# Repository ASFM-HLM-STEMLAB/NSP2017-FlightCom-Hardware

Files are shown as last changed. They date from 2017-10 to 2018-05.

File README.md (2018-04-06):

# NSP2017-FlightCom-Hardware 
ASFM Near Space Program 2017 - Flight Computer Hardware for HLM1 Capsule

- Designed in Autodesk Eagle.
- Uses Particle Electron as the master Micro Controller Unit

## Files
* HLM1_CNC : 
	This files are for creating a prototype board using a CNC such as shapeoko.
* HLM1_Oursourced : 
	This files are for sending the board to a fab house to be made such as OshPark

## PCB Manufacturing
* You may order a PCB from our [OSHPARK PROJECT R1.0](https://www.oshpark.com/projects/XPm0Xe82)
* You may order a PCB from our [OSHPARK PROJECT R2.1](https://www.adafruit.com/product/3686)
* NOTE: R2.1 includes XBee Radio. GPS IO changed to software serial.

##### Designed and created at ASFM Monterrey Mexico, 2017-2018 @ Humberto Lobo Morales STEM LAB

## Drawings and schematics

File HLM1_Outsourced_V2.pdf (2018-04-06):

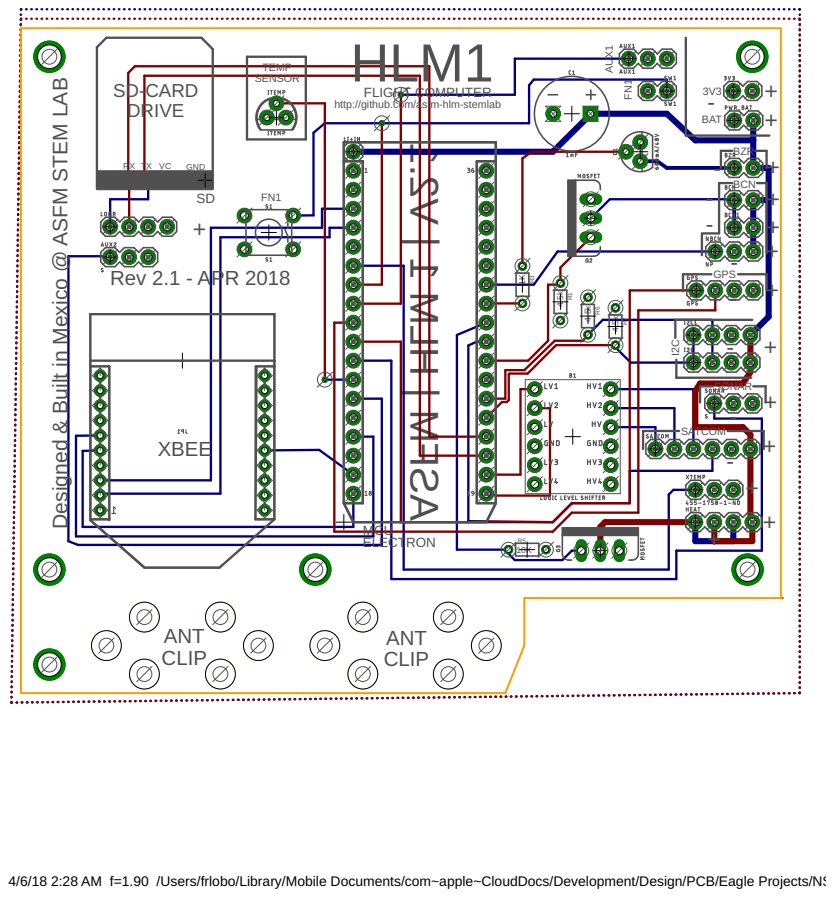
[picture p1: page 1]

4/6/18 2:28 AM f=1.90 /Users/frlobo/Library/Mobile Documents/com~apple~CloudDocs/Development/Design/PCB/Eagle Projects/NSP2/HLM1_Outsourced_V2.brd

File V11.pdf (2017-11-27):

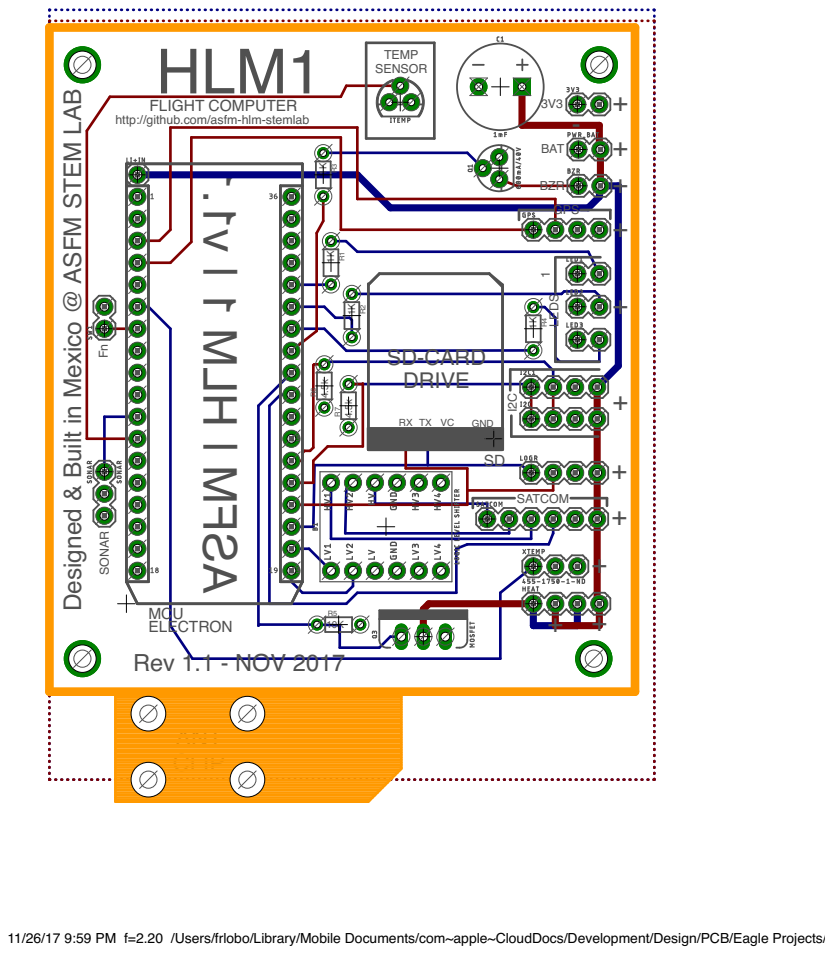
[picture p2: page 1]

FLIGHT COMPUTER
http://github.com/asfm-hlm-stemlab

DRIVE

RX TX VC GND

11/26/17 9:59 PM f=2.20 /Users/frlobo/Library/Mobile Documents/com~apple~CloudDocs/Development/Design/PCB/Eagle Projects/NSP2/HLM1_Outsourced.brd

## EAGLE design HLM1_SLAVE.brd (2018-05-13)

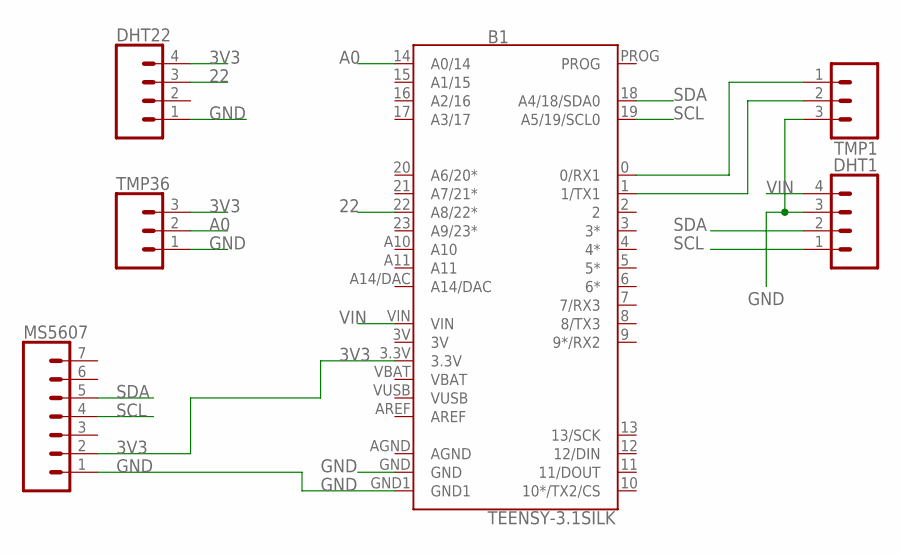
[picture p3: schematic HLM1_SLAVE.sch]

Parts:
B1: TEENSY-3.1SILK; TEENSY-3.1
DHT1, DHT22: CONN_04; 1X04
MS5607: CONN_07; 1X07
TMP1, TMP36: CONN_03; 1X03

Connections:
3V: B1.3V
3V3: B1.3.3V, DHT22.4, MS5607.2, TMP36.3
22: B1.22 (A8/22*), DHT22.3
A0: B1.14 (A0/14), TMP36.2
AGND: B1.AGND
GND: B1.GND, B1.GND1, DHT1.3, DHT22.1, MS5607.1, TMP1.3, TMP36.1
unnamed: B1.0 (0/RX1), TMP1.1
unnamed: B1.1 (1/TX1), TMP1.2
SCL: B1.19 (A5/19/SCL0), DHT1.1, MS5607.4
SDA: B1.18 (A4/18/SDA0), DHT1.2, MS5607.5
VBAT: B1.VBAT
VIN: B1.VIN, DHT1.4
VUSB: B1.VUSB

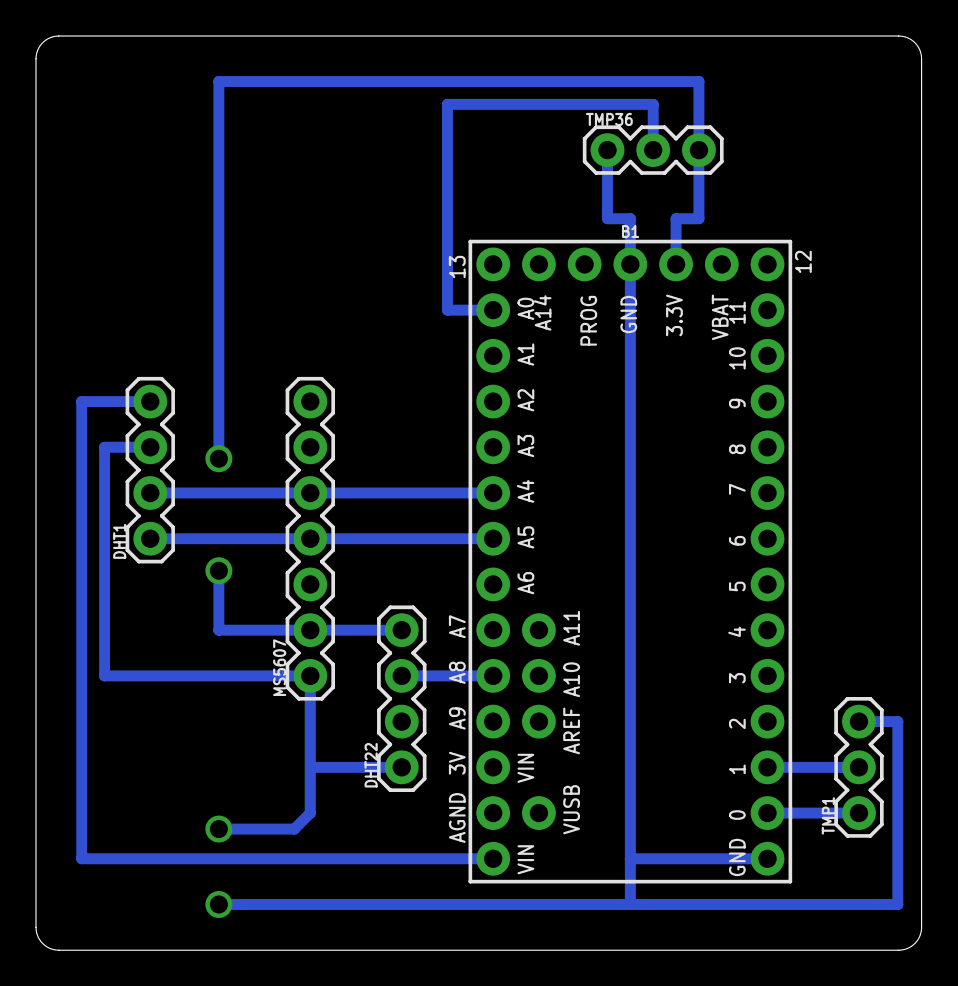
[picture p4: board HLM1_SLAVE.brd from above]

Board: 2 copper layers, 49.2 x 50.8 mm, 6 parts (0 on the bottom side), 9 nets.

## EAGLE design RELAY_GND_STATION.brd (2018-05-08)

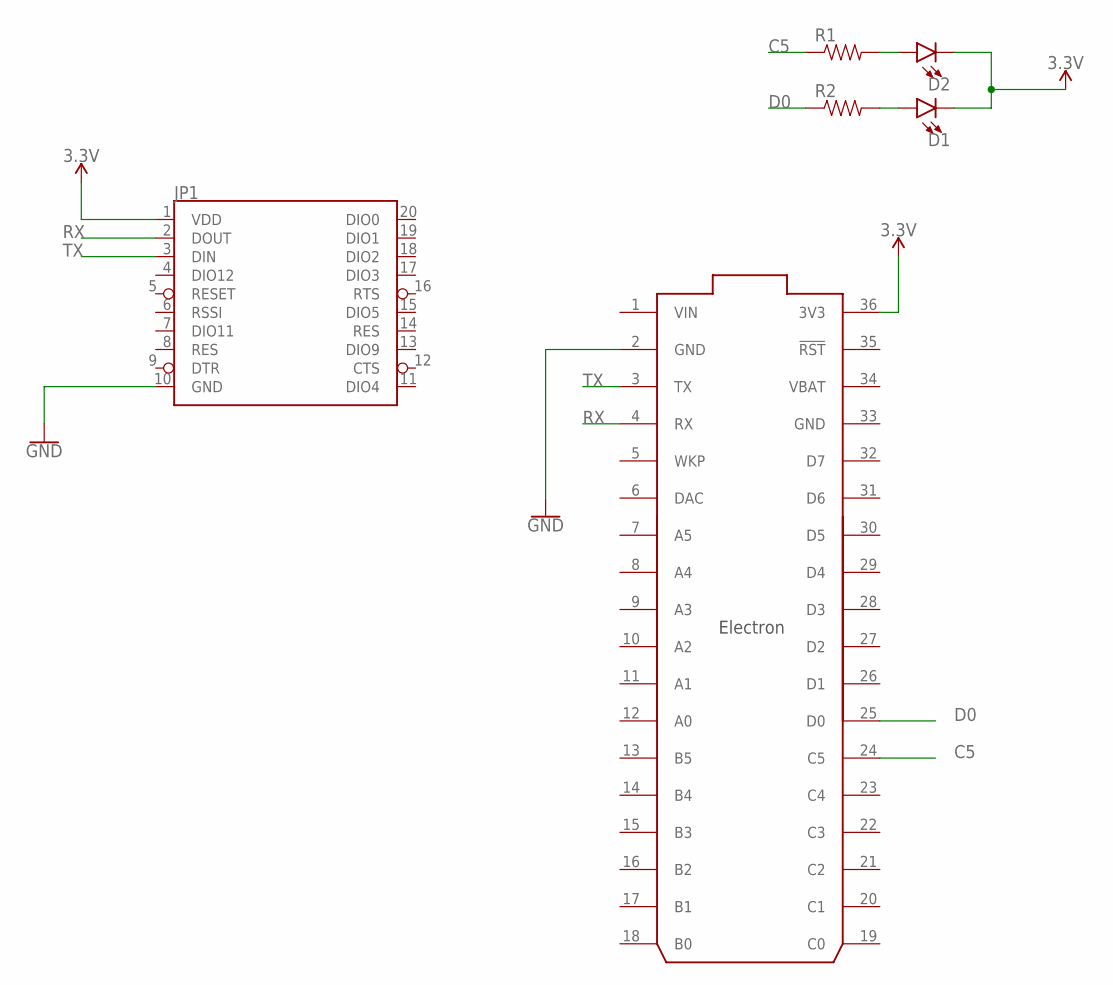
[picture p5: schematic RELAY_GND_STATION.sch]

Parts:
D1, D2: LED-3MM-NO_SILK; LED_3MM-NS
JP1: XBEELONGPAD; XBEE-LONGPAD
R1, R2: RESISTORKIT; AXIAL-0.3-KIT
U$1: ELECTRON_WITH_HEADERS; ELECTRON

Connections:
3.3V: D1.K (C), D2.K (C), JP1.1 (VDD), U$1.36 (3V3)
C5: R1.P$1 (1), U$1.24 (C5)
D0: R2.P$1 (1), U$1.25 (D0)
GND: JP1.10 (GND), U$1.2 (GND), U$1.33 (GND)
unnamed: D2.A, R1.P$2 (2)
unnamed: D1.A, R2.P$2 (2)
RX: JP1.2 (DOUT), U$1.4 (RX)
TX: JP1.3 (DIN), U$1.3 (TX)
VBAT: U$1.34 (VBAT)
VIN: U$1.1 (VIN)

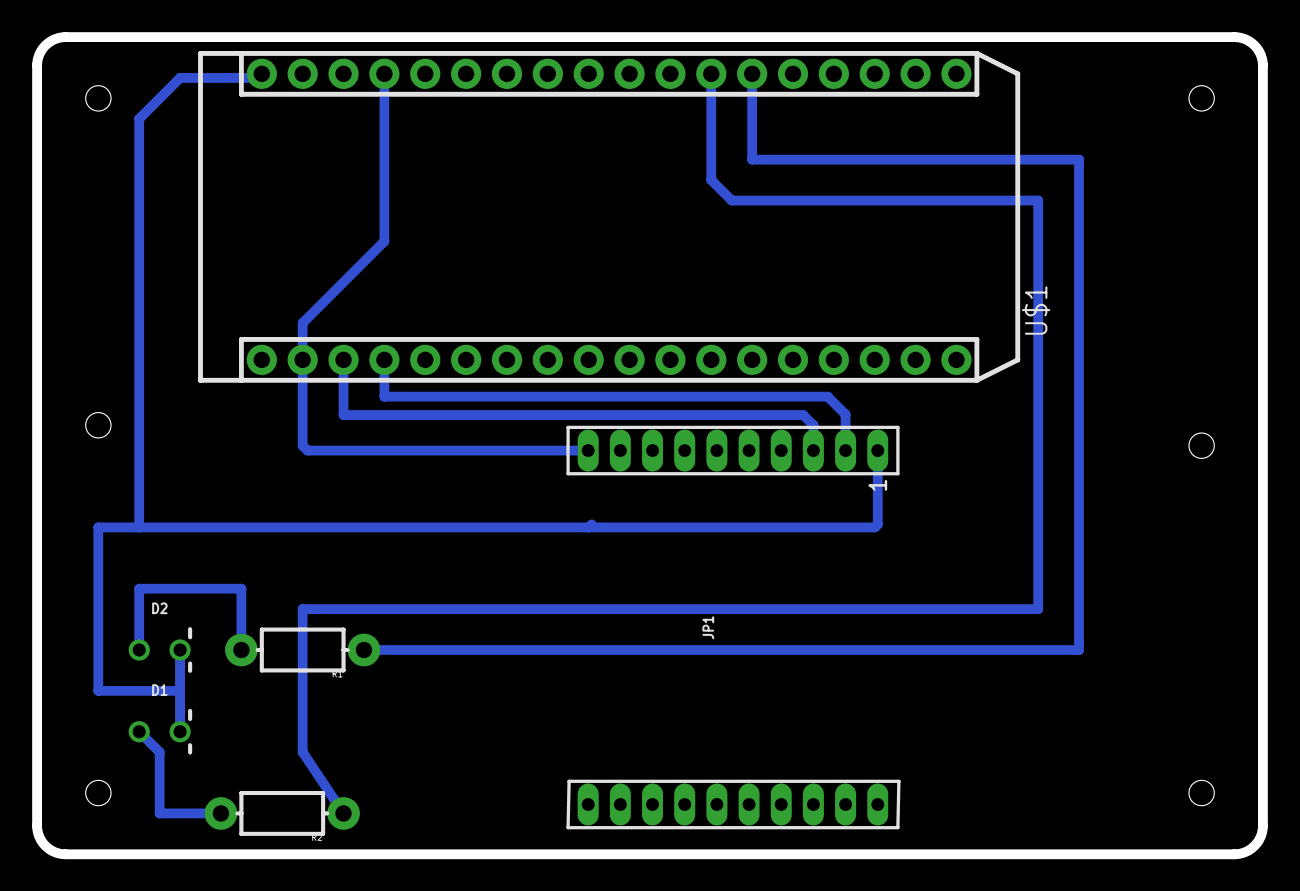
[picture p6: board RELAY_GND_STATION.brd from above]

Board: 2 copper layers, 76.2 x 50.8 mm, 6 parts (0 on the bottom side), 8 nets.

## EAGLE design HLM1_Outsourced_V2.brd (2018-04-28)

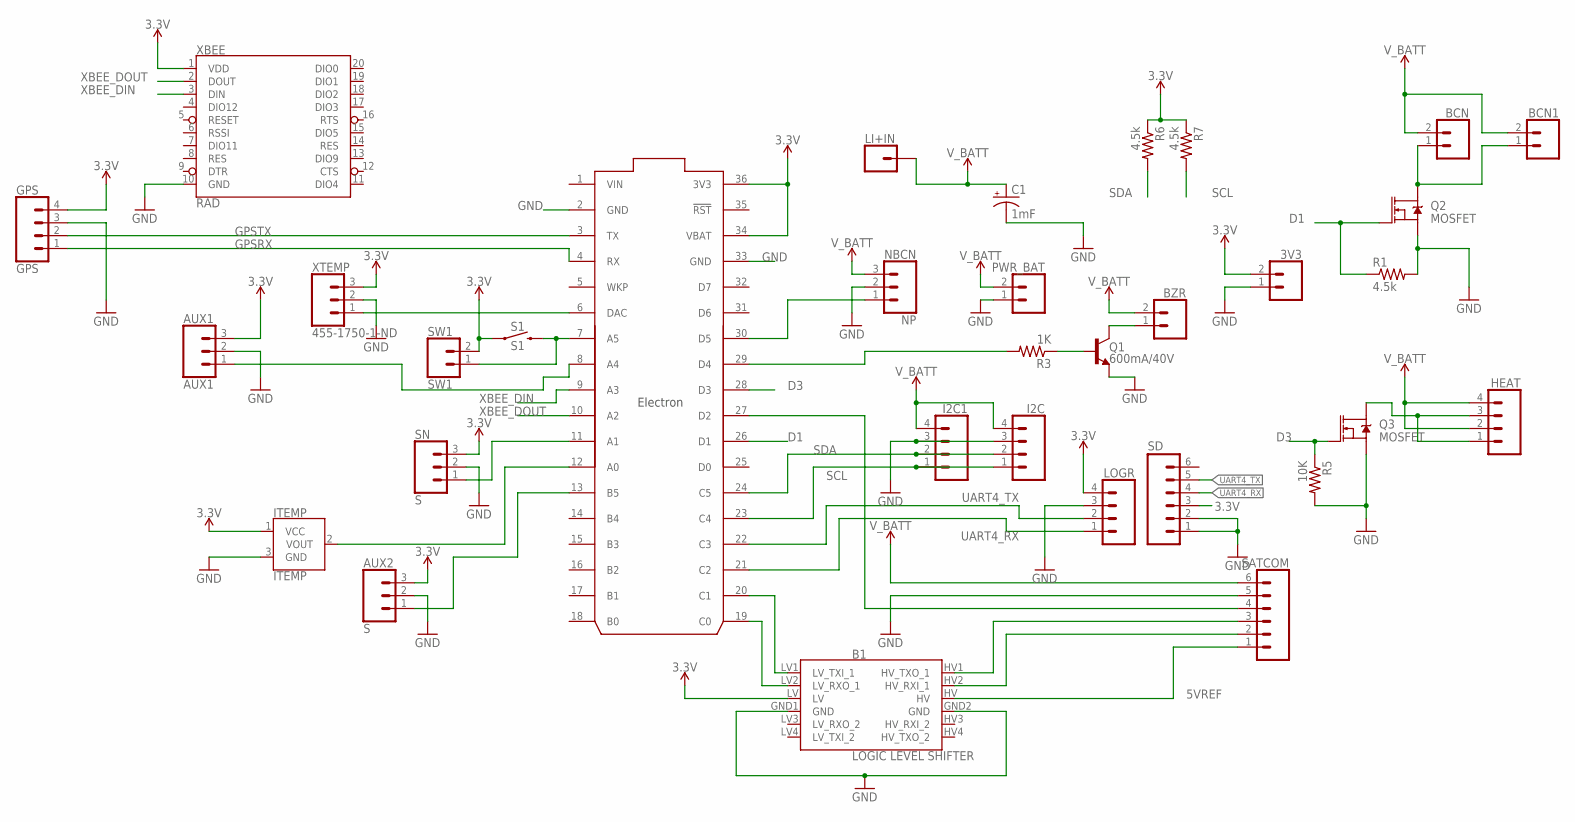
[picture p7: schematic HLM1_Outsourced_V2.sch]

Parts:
3V3: CONN_02; 1X02
AUX1: AUX1; 1X03
AUX2: S; 1X03
B1: LOGIC LEVEL SHIFTER; SPARKFUN_LOGIC_LEVEL_CONVERTER
BCN, BCN1: CONN_02; 1X02
BZR: CONN_02; 1X02
C1: 1mF; CPOL-RADIAL-5MM-10MM
GPS: GPS; 1X04
HEAT: CONN_04; 1X04
I2C, I2C1: CONN_04; 1X04
ITEMP: ITEMP; TO-92
LI+IN: CONN_01; 1X01
LOGR: CONN_04; 1X04
MCU: ELECTRON
NBCN: NP; 1X03
PWR_BAT: CONN_02; 1X02
Q1: 600mA/40V; TO-92
Q2, Q3: MOSFET; TO220V
R1, R6, R7: 4.5k; 1/6W-RES
R3: 1K; 1/6W-RES
R5: 10K; 1/6W-RES
S1: S1; TACTILE_SWITCH_PTH_6.0MM
SATCOM: CONN_06SILK_FEMALE_PTH; 1X06@1
SD: M06NO_SILK_FEMALE_PTH; 1X06_NO_SILK
SN: S; 1X03
SW1: SW1; 1X02
XBEE: RAD; XBEE-LONGPAD
XTEMP: 455-1750-1-ND; 1X03

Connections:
3.3V: 3V3.2, AUX1.3, AUX2.3, B1.LV, GPS.4, ITEMP.1 (VCC), LOGR.4, MCU.34 (VBAT), MCU.36 (3V3), R6.1, R7.1, S1.1, SD.3, SN.3, SW1.2, XBEE.1 (VDD), XTEMP.3
5VREF: B1.HV, SATCOM.1
D1: MCU.26 (D1), Q2.1 (G), R1.1
D3: MCU.28 (D3), Q3.1 (G), R5.1
GND: 3V3.1, AUX1.2, AUX2.2, B1.GND1 (GND), B1.GND2 (GND), C1.-, GPS.3, I2C.3, I2C1.3, ITEMP.3 (GND), LOGR.3, MCU.2 (GND), MCU.33 (GND), NBCN.2, PWR_BAT.1, Q1.3 (E), Q2.3 (S), Q3.3 (S), R1.2, R5.2, SATCOM.5, SD.1, SD.2, SN.2, XBEE.10 (GND), XTEMP.2
GPSRX: GPS.1, MCU.4 (RX)
GPSTX: GPS.2, MCU.3 (TX)
IRWKP: MCU.27 (D2), SATCOM.4
unnamed: MCU.6 (DAC), XTEMP.1
unnamed: MCU.29 (D4), R3.2
unnamed: Q1.2 (B), R3.1
unnamed: MCU.30 (D5), NBCN.1
unnamed: B1.LV1 (LV_TXI_1), MCU.20 (C1)
unnamed: B1.LV2 (LV_RXO_1), MCU.19 (C0)
unnamed: BZR.1, Q1.1 (C)
unnamed: B1.HV1 (HV_TXO_1), SATCOM.3
unnamed: HEAT.1, HEAT.3, Q3.2 (D)
unnamed: BCN.1, BCN1.1, Q2.2 (D)
unnamed: B1.HV2 (HV_RXI_1), SATCOM.2
unnamed: MCU.7 (A5), S1.3 (2), SW1.1
unnamed: MCU.11 (A1), SN.1
unnamed: ITEMP.2 (VOUT), MCU.12 (A0)
unnamed: AUX2.1, MCU.13 (B5)
unnamed: AUX1.1, MCU.8 (A4)
SCL: I2C.1, I2C1.1, MCU.23 (C4), R7.2
SDA: I2C.2, I2C1.2, MCU.24 (C5), R6.2
UART4_RX: LOGR.1, MCU.21 (C2), SD.4
UART4_TX: LOGR.2, MCU.22 (C3), SD.5
VIN: MCU.1 (VIN)
V_BATT: BCN.2, BCN1.2, BZR.2, C1.+, HEAT.2, HEAT.4, I2C.4, I2C1.4, LI+IN.1, NBCN.3, PWR_BAT.2, SATCOM.6
XBEE_DIN: MCU.9 (A3), XBEE.3 (DIN)
XBEE_DOUT: MCU.10 (A2), XBEE.2 (DOUT)

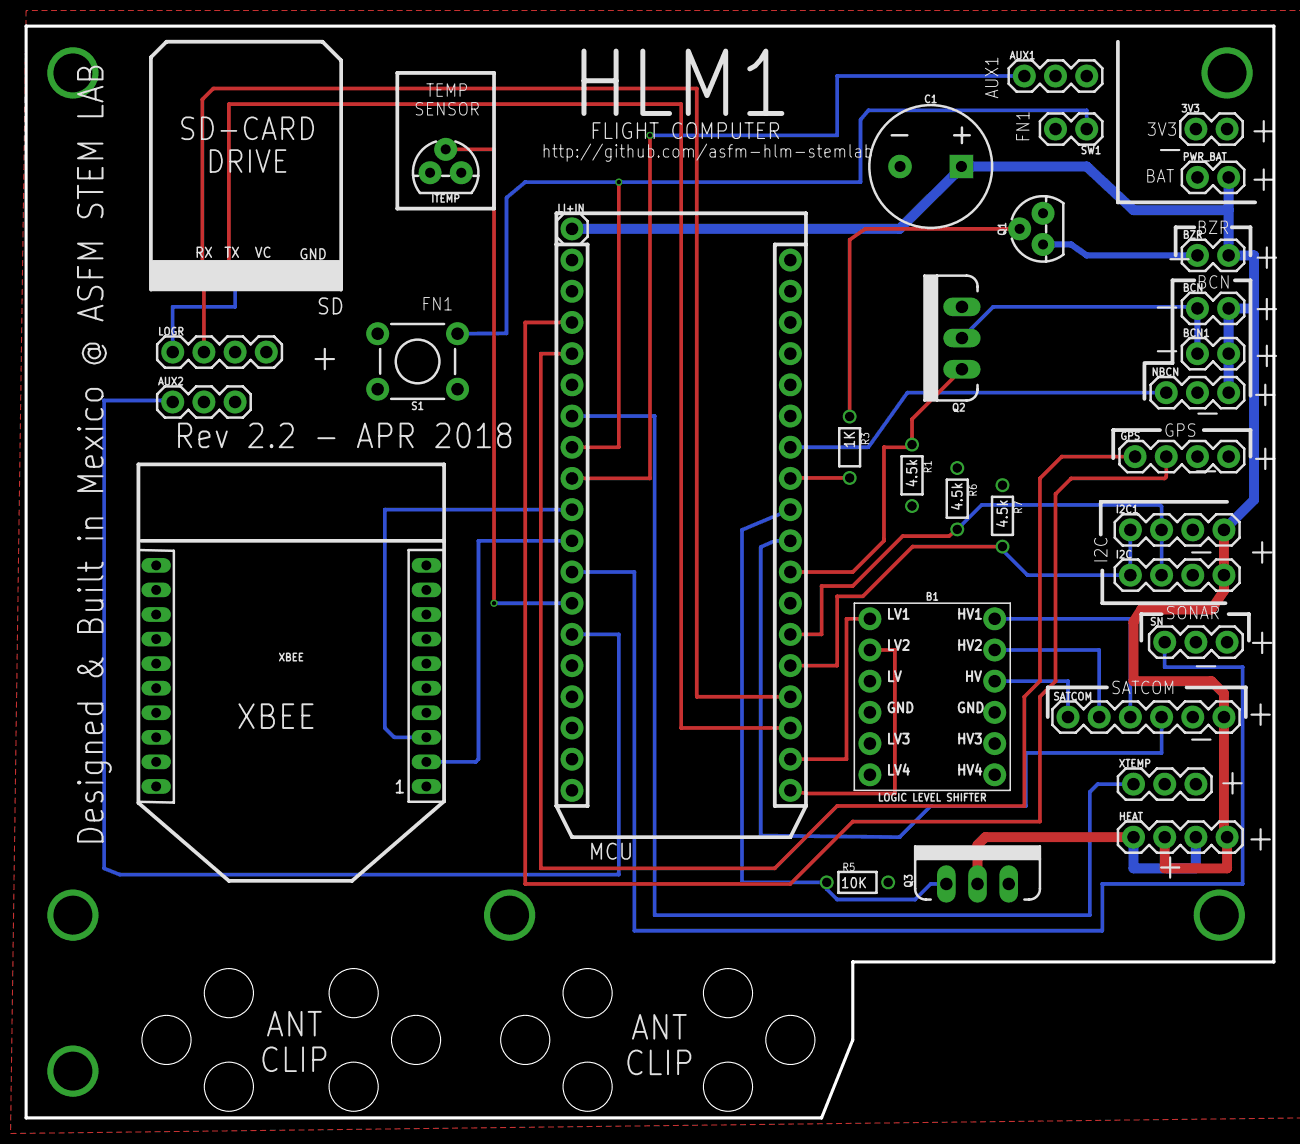
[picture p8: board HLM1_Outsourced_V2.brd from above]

Board: 2 copper layers, 101.6 x 88.9 mm, 33 parts (0 on the bottom side), 31 nets.

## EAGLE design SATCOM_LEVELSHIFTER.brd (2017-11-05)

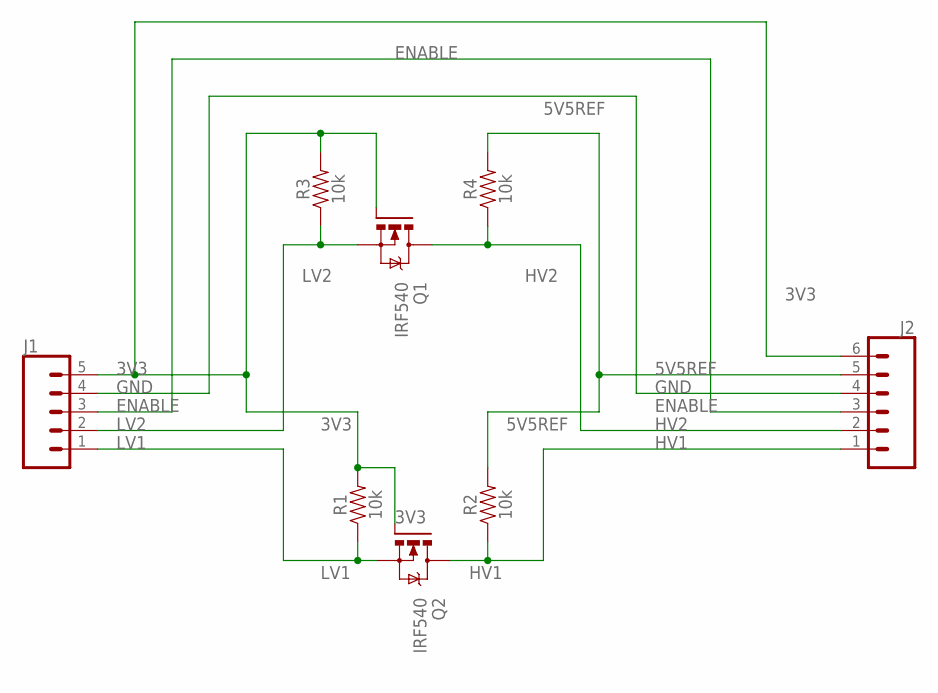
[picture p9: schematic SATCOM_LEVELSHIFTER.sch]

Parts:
J1: CONN_05PTH_LONGPADS; 1X05_LONGPADS
J2: CONN_06LONGPADS; 1X06_LONGPADS
Q1, Q2: IRF540; TO220BV
R1, R2, R3, R4: 10k; AXIAL-0.3-KIT

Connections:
3V3: J1.5, J2.6, Q1.G, Q2.G, R1.P$2 (2), R3.P$2 (2)
5V5REF: J2.5, R2.P$2 (2), R4.P$2 (2)
ENABLE: J1.3, J2.3
GND: J1.4, J2.4
HV1: J2.1, Q2.D, R2.P$1 (1)
HV2: J2.2, Q1.D, R4.P$1 (1)
LV1: J1.1, Q2.S, R1.P$1 (1)
LV2: J1.2, Q1.S, R3.P$1 (1)

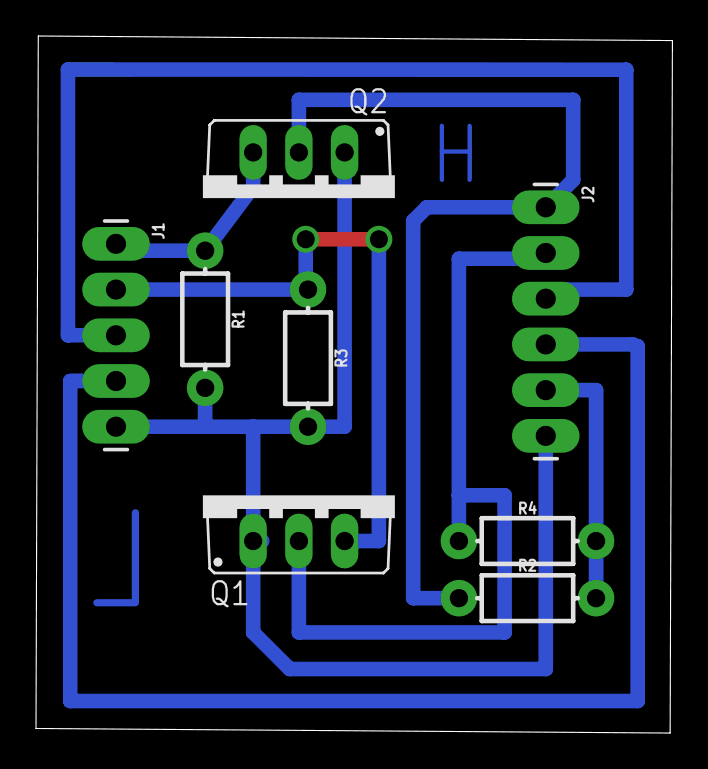
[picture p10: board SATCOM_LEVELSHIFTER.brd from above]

Board: 2 copper layers, 35.4 x 38.7 mm, 8 parts (0 on the bottom side), 8 nets.

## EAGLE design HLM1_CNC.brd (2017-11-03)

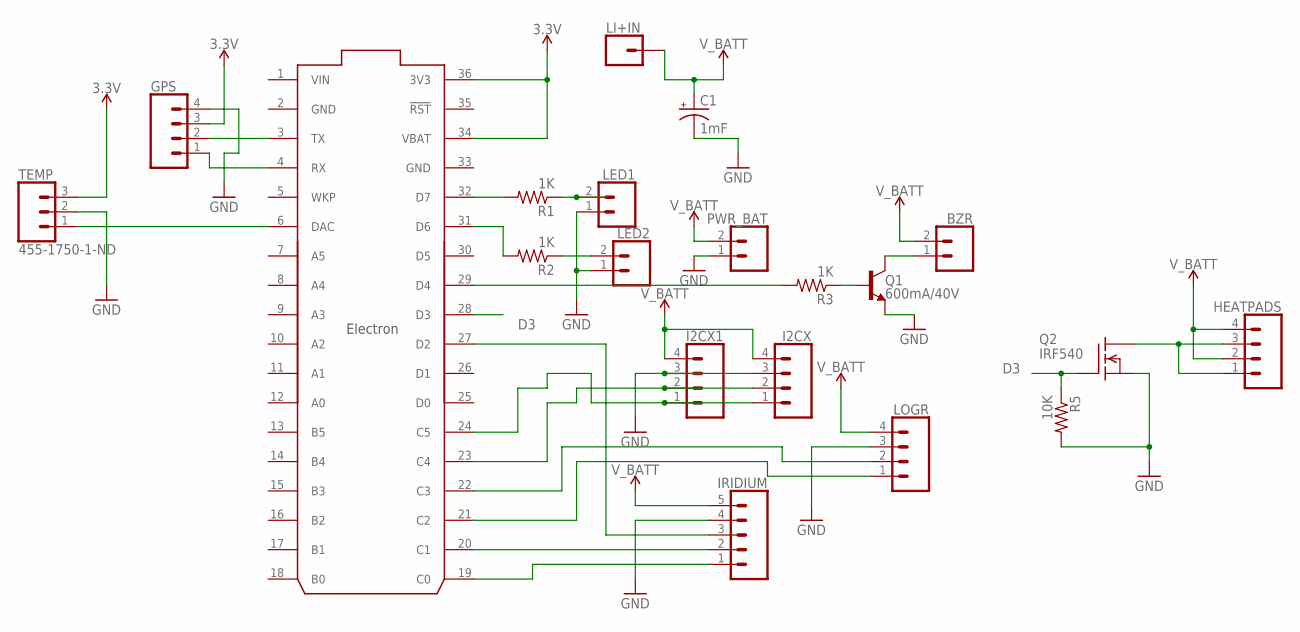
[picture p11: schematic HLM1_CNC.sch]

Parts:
BZR: CONN_02; 1X02
C1: 1mF; CPOL-RADIAL-5MM-10MM
GPS: CONN_04; 1X04
HEATPADS: CONN_04; 1X04
I2CX, I2CX1: CONN_04; 1X04
IRIDIUM: CONN_05; 1X05
LED1, LED2: CONN_02; 1X02
LI+IN: CONN_01; 1X01
LOGR: CONN_04; 1X04
PWR_BAT: CONN_02; 1X02
Q1: 600mA/40V; TO-92
Q2: IRF540; TO220
R1, R2, R3: 1K; 1/6W-RES
R5: 10K; 1/6W-RES
TEMP: 455-1750-1-ND; 1X03
U$1: ELECTRON_WITH_HEADERS; ELECTRON

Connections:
3.3V: GPS.3, TEMP.3, U$1.34 (VBAT), U$1.36 (3V3)
BASE: Q1.2 (B), R3.1
D3: Q2.1 (G), R5.1, U$1.28 (D3)
GND: C1.-, GPS.4, I2CX.3, I2CX1.3, IRIDIUM.4, LED1.1, LED2.1, LOGR.3, PWR_BAT.1, Q1.3 (E), Q2.3 (S), R5.2, TEMP.2, U$1.2 (GND), U$1.33 (GND)
IRWKP: IRIDIUM.3, U$1.27 (D2)
unnamed: TEMP.1, U$1.6 (DAC)
unnamed: R1.2, U$1.32 (D7)
unnamed: R3.2, U$1.29 (D4)
unnamed: LED1.2, R1.1
unnamed: BZR.1, Q1.1 (C)
unnamed: HEATPADS.1, HEATPADS.3, Q2.2 (D)
unnamed: R2.2, U$1.31 (D6)
unnamed: IRIDIUM.2, U$1.20 (C1)
unnamed: I2CX.1, I2CX1.1, U$1.24 (C5)
unnamed: LED2.2, R2.1
RX: GPS.1, U$1.4 (RX)
SDA: I2CX.2, I2CX1.2, U$1.23 (C4)
TX: GPS.2, U$1.3 (TX)
UART4_RX: LOGR.1, U$1.21 (C2)
UART4_TX: LOGR.2, U$1.22 (C3)
UART5_RX: IRIDIUM.1, U$1.19 (C0)
VIN: U$1.1 (VIN)
V_BATT: BZR.2, C1.+, HEATPADS.2, HEATPADS.4, I2CX.4, I2CX1.4, IRIDIUM.5, LI+IN.1, LOGR.4, PWR_BAT.2

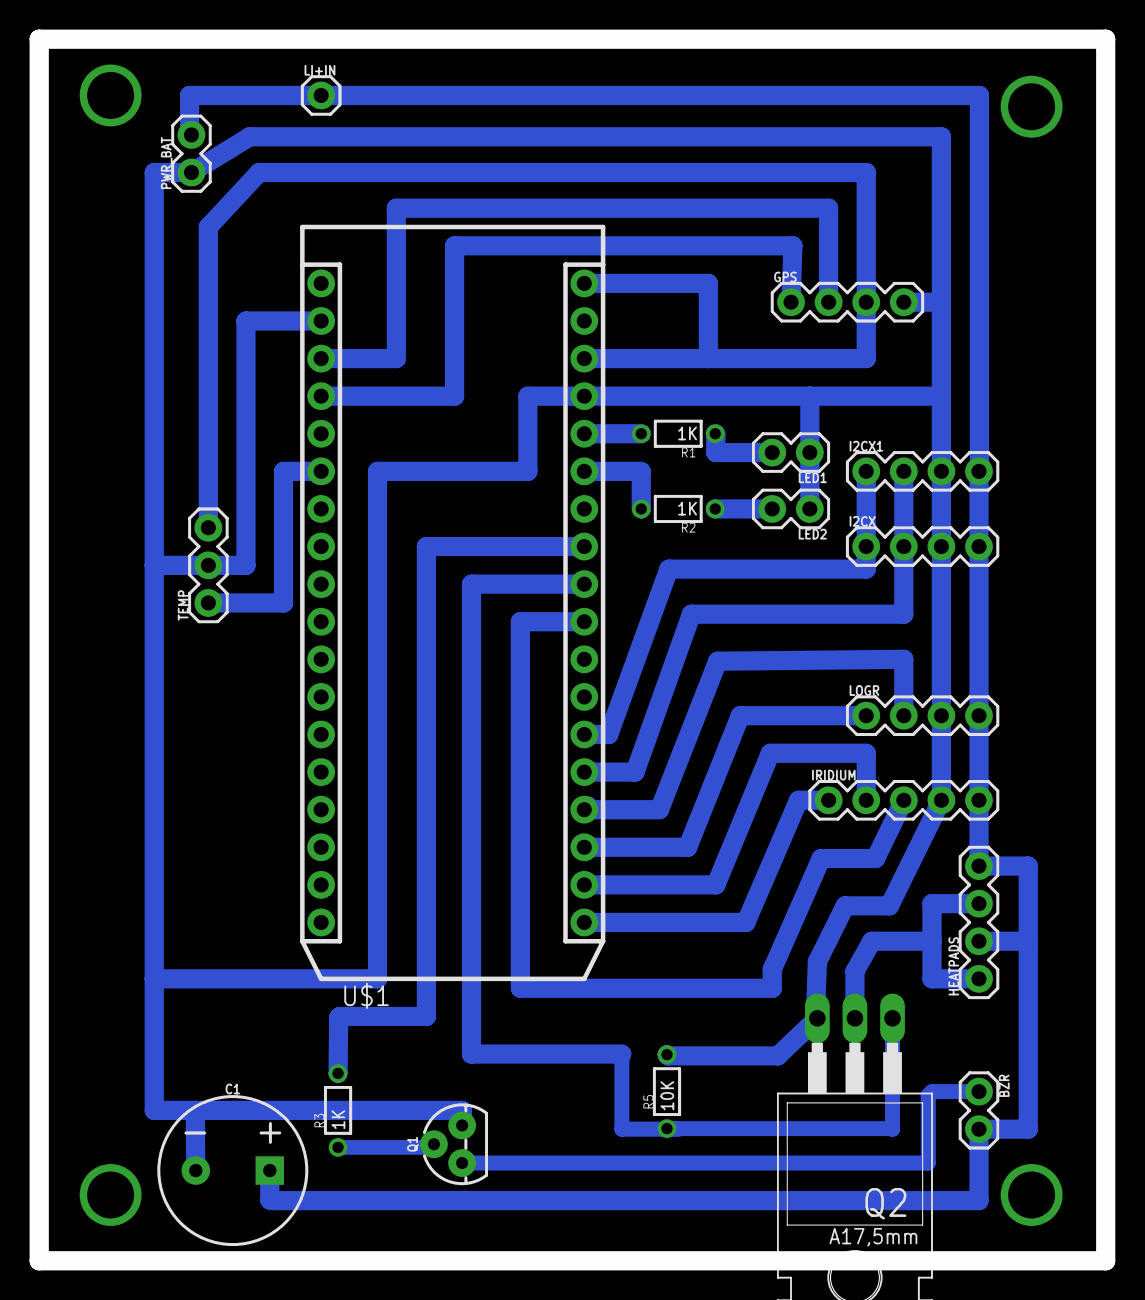
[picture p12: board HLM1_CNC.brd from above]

Board: 2 copper layers, 72.1 x 82.5 mm, 20 parts (0 on the bottom side), 22 nets.

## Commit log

2017-10-24 Added routes to PCB in 1 Lauyer (VC)
    [NSP2C.brd, NSP2C.sch]
2017-10-24 Made width of wires thicker (1.00mm)
    [NSP2C.brd]
2017-10-24 Improved routing
    [NSP2C.brd, NSP2C.sch]
2017-10-26 Added new PCB design for outsource manufacturing
    [NSP2D.brd, NSP2D.sch]
2017-10-26 Added missing pullup resistors to SCL SDA for I2C bus
    [NSP2D.brd, NSP2D.sch]
2017-10-31 Added capacitor for batt source
    [NSP2C.brd, NSP2C.sch, NSP2D.brd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]
2017-10-31 Finished R1 for manufacturing
    [NSP2D.brd, NSP2D.sch]
2017-11-03 Improved naming and file structure
    [HLM1_CNC_B.brd, HLM1_CNC_B.sch, HLM1_Outsourced_A.brd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]
2017-11-03 Improved naming conventions for GIT
    [HLM1_CNC.brd, HLM1_CNC.sch, HLM1_Outsourced.brd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]
2017-11-05 Added onboard level shifter to outsourced design and other improvements
    [HLM1_Outsourced.brd, HLM1_Outsourced.sch, SATCOM_LEVELSHIFTER.brd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]
2017-11-05 Added onboard SD CARD + Sonar Port for touchdown detection
    [HLM1_Outsourced.brd, HLM1_Outsourced.sch]
2017-11-05 Improved design and labels
    [HLM1_Outsourced.brd, HLM1_Outsourced.sch]
2017-11-27 Added PCB V1.1 PDF for reference
2018-02-02 Minor Updates
    [HLM1_Outsourced.brd, HLM1_Outsourced.sch]
2018-04-06 Implemented version 2.1 for XBee Radio + Improvements throughout
    [HLM1_Outsourced_V2.brd, HLM1_Outsourced_V2.sch]
2018-04-28 Updated flight board to add XBee radio
    [HLM1_Outsourced_V2.brd, HLM1_Outsourced_V2.sch]
2018-05-07 Slave board added
    [HLM1_SLAVE.brd, HLM1_SLAVE.sch]
2018-05-13 Connected I2C lines to slave device for board carving
    [HLM1_SLAVE.brd, HLM1_SLAVE.sch]

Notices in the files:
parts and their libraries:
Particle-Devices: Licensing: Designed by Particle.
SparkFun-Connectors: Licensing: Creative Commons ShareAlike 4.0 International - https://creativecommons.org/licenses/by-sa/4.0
